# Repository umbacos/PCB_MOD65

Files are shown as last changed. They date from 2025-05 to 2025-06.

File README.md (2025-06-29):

# Mod65 Keyboard

![Mod65]

* **Keyboard Maintainer**: [umbacos](https://github.com/umbacos)
* **Firmware**: [QMK](https://qmk.fm/)
* **Source**: https://github.com/umbacos/MOD65

MOD65 is a custom mechanical keyboard designed and built 
by [umbacos](https://github.com/umbacos). It features a custom PCB based on
the [Aryess](https://github.com/pioz/aryess_keyboard) design but with some
improvements and differences.

## Features

* **RP2040 Pro Micro**
* **68% ANSI layout**
* **Rotary encoder (knob)**
* **[Unified Daughterboard](https://unified-daughterboard.github.io)** support
* **RGB Matrix LEDs** (per-key RGB lighting)
* **Underglow LED strip**
* **Configurable physical toggle switch**
* **OLED display**
* **O-ring gasket mount** (Friction fit)
* **PCB compatible with most 68% cases **
* **Built-in [Pomodoro Timer](https://en.wikipedia.org/wiki/Pomodoro_Technique)**
* **Fully open source**
  * **PCB and plate designed with [KiCad 9](https://www.kicad.org/)**
  * **Case designed with [Autodesk Fusion 360](https://www.autodesk.com/products/fusion-360/overview/)**

## Built it yourself

You can build your own **MOD65** keyboard by following these steps.

### Order the PCB and Plate

The PCB and plate production files are ready for you. You only need to upload them to JLCPCB:

* **PCB Production File:** `pcb/production/mod65_2.zip`
* **Plate Production File:** `plate/production/mod65_plate_2.zip`

Go to [https://jlcpcb.com/](https://jlcpcb.com/), and upload both files.

When ordering the PCB:

* Select the **PCB Assembly** option.
* JLCPCB will take care of soldering the components for you.
* Minimum order quantity is 5 units.

You will receive fully assembled PCBs at home.

### Order the Case

For the case, upload the file `case/MOD65 Case.step` to a 3D printing service.
You can use any 3D printing service if you prefer.

### Purchase the Extra Components

You will need some additional components. Here is the full list with purchase links:

| Component | Description | Purchase Link |
| --- | --- | --- |
| **OLED Display** | SSD1306 OLED 128 x 32 | [Buy on Amazon](https://www.amazon.it/dp/B079H2C7WH) |
| **JST Cables** | 3x JST 4-pin 1mm pitch cables | |
| | 1x JST 3-pin 1mm pitch cable | |
| **Rubber Feet** | Round 20mm diameter rubber feet | [Buy on Amazon](https://www.amazon.it/dp/B089SH84C4) |
| **Rotary Encoder** | Rotary encorder (EC11 compatible) | [Buy on Amazon](https://www.amazon.it/dp/B0B63YN466) |
| **Knob** | Metal knob for rotary encoder | [Buy on Amazon](https://www.amazon.it/dp/B0CRRDYKQK) |
| **LED Strip** | APA102-compatible LED strip, \~27.5cm | [Buy on Amazon](https://www.amazon.it/dp/B0B3HDNFVM) |
| **Stabilizers** | MX compatible keyboard stabilizers | [Buy on Amazon](https://www.amazon.it/dp/B01LW5B69T) |
| **Toggle Switch** | On/Off switch | [Buy on Amazon](https://www.amazon.it/dp/B07J4KB38W) |
| **Unified Daughterboard** | USB-C daughterboard | [Buy on 42keebs](https://42keebs.eu/shop/parts/unified-daughterboard-udb-c3-c4-c5/?attribute_version=C5%20JSH) |
| **O-Ring Gasket** | VMQ-50 (Silicone 50 duro), AS568-264  | [Buy on Amazon](https://www.amazon.it/dp/B07CVKV6DV) |
| **Foam Sheet** | Foam for case/PCB dampening | [Buy on Amazon](https://www.amazon.it/dp/B0CNVRGXWB) |

Some items can be found from different sellers depending on your country.

### Assembly

Once you have received the PCB, plate, case, and all components, you can start assembling your MOD65 keyboard.

## Compile the Firmware

```sh
qmk compile -kb umbacos/mod65 -km default
```

This command compiles the firmware for the MOD65 keyboard using the `default` keymap.

---

## Flash the Firmware

To flash the firmware, you must enter **boot mode** on the PCB.

### Entering Boot Mode

* If no firmware is present, connecting the board via USB will automatically
  enter boot mode.
* If firmware is already flashed:

  * Hold the **BOOT** button located on the PCB, then plug in the USB
    cable. Release the button once connected.
  * Alternatively, if this firmware is already running, press the key
    combination: `FN2 + ENTER`.

### Flashing

Once in boot mode, your computer should detect a new USB mass storage device
named something like `RPI-RP2`.

Copy the compiled `.uf2` file (e.g., `umbacos/mod65_default.uf2`) directly into the
root of that device. The board will automatically flash and reboot with the
new firmware.

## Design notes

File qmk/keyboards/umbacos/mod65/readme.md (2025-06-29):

# MOD65 Keyboard

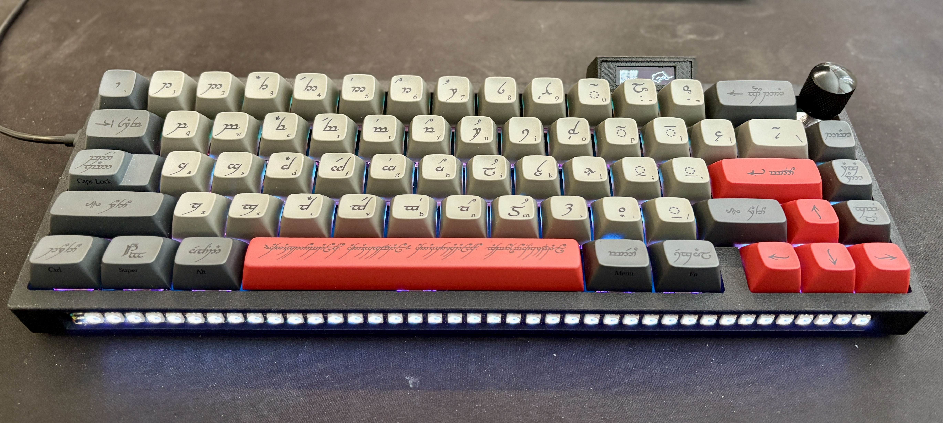
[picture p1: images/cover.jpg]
MOD65


* **Keyboard Maintainer**: [umbacos](https://github.com/umbacos)
* **Firmware**: [QMK](https://qmk.fm/)
* **Source**: https://github.com/umbacos/MOD65_keyboard

MOD65 is a custom mechanical keyboard designed and built from the ground up
by [umbacos](https://github.com/umbacos). It features a completely custom PCB and a
wide range of modern features for both productivity and aesthetics.

## Features

* **RP2040 Pro Micro**
* **65% ANSI layout**
* **Rotary encoder (knob)**
* **[Unified Daughterboard](https://unified-daughterboard.github.io)** support
* **RGB Matrix LEDs** (per-key RGB lighting)
* **Underglow LED strip**
* **Configurable physical toggle switch**
* **OLED display**
* **O-ring gasket mount** (Friction fit)
* **PCB compatible with [Bakeneko](https://github.com/kkatano/bakeneko-65) case**
* **Built-in [Pomodoro Timer](https://en.wikipedia.org/wiki/Pomodoro_Technique)**
* **Fully open source**
  * **PCB and plate designed with [KiCad 9](https://www.kicad.org/)**
  * **Case designed with [Autodesk Fusion 360](https://www.autodesk.com/products/fusion-360/overview/)**

---

## Compile the Firmware

```sh
qmk compile -kb MOD65 -km default
```

This command compiles the firmware for the MOD65 keyboard using the `default` keymap.

---

## Flash the Firmware

To flash the firmware, you must enter **boot mode** on the PCB.

### Entering Boot Mode

* If no firmware is present, connecting the board via USB will automatically
  enter boot mode.
* If firmware is already flashed:

  * Hold the **BOOT** button located underneath the PCB, then plug in the USB
    cable. Release the button once connected.
  * Alternatively, if this firmware is already running, press the key
    combination: `FN2 + ENTER`.

### Flashing

Once in boot mode, your computer should detect a new USB mass storage device
named something like `RPI-RP2`.

Copy the compiled `.uf2` file (e.g., `MOD65_default.uf2`) directly into the
root of that device. The board will automatically flash and reboot with the
new firmware.

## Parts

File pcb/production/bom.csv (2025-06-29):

Designator | Footprint | Quantity | Value | LCSC Part #
BTN1 | SW_SPST_TL3342 | 1 | RESET | C2886898
BTN2 | SW_SPST_TL3342 | 1 | BOOT | C2886898
C1, C10, C11, C2, C3, C4, C5, C6, C7, C8, C9 | 0805 | 11 | 100nf | C28233
C12, C13, C16, C17 | 0805 | 4 | 1uf | C28323
C14, C15 | 0805 | 2 | 22pf | C1804
D1, D10, D11, D12, D13, D14, D15, D16, D17, D18, D19, D2, D20, D21, D22, D23, D24, D25, D26, D27, D28, D29, D3, D30, D31, D32, D33, D34, D35, D36, D37, D38, D39, D4, D40, D41, D42, D43, D44, D45, D46, D47, D48, D49, D5, D50, D51, D52, D53, D54, D55, D56, D57, D58, D59, D6, D60, D61, D62, D63, D64, D65, D66, D67, D68, D7, D8, D9 | D_SOD-323 | 68 | D | C2128
J1 | JST_SH_SM04B-SRSS-TB_1x04-1MP_P1.00mm_Horizontal | 1 | UD | C160404
J2 | JST_SH_SM04B-SRSS-TB_1x04-1MP_P1.00mm_Horizontal | 1 | OLED | C160404
J3 | JST_SH_SM04B-SRSS-TB_1x04-1MP_P1.00mm_Horizontal | 1 | LEDs | C160404
J4 | JST_SH_SM03B-SRSS-TB_1x03-1MP_P1.00mm_Horizontal | 1 | Switch | C160403
LED1, LED10, LED11, LED12, LED13, LED14, LED15, LED16, LED17, LED18, LED19, LED2, LED20, LED21, LED22, LED23, LED24, LED25, LED26, LED27, LED28, LED29, LED3, LED30, LED31, LED32, LED33, LED34, LED35, LED36, LED37, LED38, LED39, LED4, LED40, LED41, LED42, LED43, LED44, LED45, LED46, LED47, LED48, LED49, LED5, LED50, LED51, LED52, LED53, LED54, LED55, LED56, LED57, LED58, LED59, LED6, LED60, LED61, LED62, LED63, LED64, LED65, LED66, LED67, LED68, LED7, LED8, LED9 | LED_6028R | 68 | SK6812MINI-E | C5149201
R1, R4, R5 | 0805 | 3 | 10k | C17414
R2, R3 | 0805 | 2 | 27 | C17594
R6 | 0805 | 1 | 1k | C17513
SW1 | SW_MX_HS_CPG151101S11_1u | 1 | ESC | C41430893
SW10 | SW_MX_HS_CPG151101S11_1u | 1 | 9 | C41430893
SW11 | SW_MX_HS_CPG151101S11_1u | 1 | 0 | C41430893
SW12 | SW_MX_HS_CPG151101S11_1u | 1 | - | C41430893
SW13 | SW_MX_HS_CPG151101S11_1u | 1 | = | C41430893
SW14 | SW_MX_HS_CPG151101S11_1u | 1 | BACK | C41430893
SW15 | SW_MX_HS_CPG151101S11_1u | 1 | Del | C41430893
SW15E1 | ROT_Alps_EC11E-Switch | 1 | SW15
SW16 | SW_MX_HS_CPG151101S11_1u | 1 | TAB | C41430893
SW17 | SW_MX_HS_CPG151101S11_1u | 1 | Q | C41430893
SW18 | SW_MX_HS_CPG151101S11_1u | 1 | W | C41430893
SW19 | SW_MX_HS_CPG151101S11_1u | 1 | E | C41430893
SW2 | SW_MX_HS_CPG151101S11_1u | 1 | 1 | C41430893
SW20 | SW_MX_HS_CPG151101S11_1u | 1 | R | C41430893
SW21 | SW_MX_HS_CPG151101S11_1u | 1 | T | C41430893
SW22 | SW_MX_HS_CPG151101S11_1u | 1 | Y | C41430893
SW23 | SW_MX_HS_CPG151101S11_1u | 1 | U | C41430893
SW24 | SW_MX_HS_CPG151101S11_1u | 1 | I | C41430893
SW25 | SW_MX_HS_CPG151101S11_1u | 1 | O | C41430893
SW26 | SW_MX_HS_CPG151101S11_1u | 1 | P | C41430893
SW27 | SW_MX_HS_CPG151101S11_1u | 1 | [ | C41430893
SW28 | SW_MX_HS_CPG151101S11_1u | 1 | ] | C41430893
SW29 | SW_MX_HS_CPG151101S11_1u | 1 | \ | C41430893
SW3 | SW_MX_HS_CPG151101S11_1u | 1 | 2 | C41430893
SW30 | SW_MX_HS_CPG151101S11_1u | 1 | PgUp | C41430893
SW31 | SW_MX_HS_CPG151101S11_1u | 1 | CAPS | C41430893
SW32 | SW_MX_HS_CPG151101S11_1u | 1 | A | C41430893
SW33 | SW_MX_HS_CPG151101S11_1u | 1 | S | C41430893
SW34 | SW_MX_HS_CPG151101S11_1u | 1 | D | C41430893
SW35 | SW_MX_HS_CPG151101S11_1u | 1 | F | C41430893
SW36 | SW_MX_HS_CPG151101S11_1u | 1 | G | C41430893
SW37 | SW_MX_HS_CPG151101S11_1u | 1 | H | C41430893
SW38 | SW_MX_HS_CPG151101S11_1u | 1 | J | C41430893
SW39 | SW_MX_HS_CPG151101S11_1u | 1 | K | C41430893
SW4 | SW_MX_HS_CPG151101S11_1u | 1 | 3 | C41430893
SW40 | SW_MX_HS_CPG151101S11_1u | 1 | L | C41430893
SW41 | SW_MX_HS_CPG151101S11_1u | 1 | ; | C41430893
SW42 | SW_MX_HS_CPG151101S11_1u | 1 | ' | C41430893
SW43 | SW_MX_HS_CPG151101S11_1u | 1 | ENTER | C41430893
SW44 | SW_MX_HS_CPG151101S11_1u | 1 | PgDn | C41430893
SW45 | SW_MX_HS_CPG151101S11_1u | 1 | LSHIFT | C41430893
SW46 | SW_MX_HS_CPG151101S11_1u | 1 | Z | C41430893
SW47 | SW_MX_HS_CPG151101S11_1u | 1 | X | C41430893
SW48 | SW_MX_HS_CPG151101S11_1u | 1 | C | C41430893
SW49 | SW_MX_HS_CPG151101S11_1u | 1 | V | C41430893
SW5 | SW_MX_HS_CPG151101S11_1u | 1 | 4 | C41430893
SW50 | SW_MX_HS_CPG151101S11_1u | 1 | B | C41430893
SW51 | SW_MX_HS_CPG151101S11_1u | 1 | N | C41430893
SW52 | SW_MX_HS_CPG151101S11_1u | 1 | M | C41430893
SW53 | SW_MX_HS_CPG151101S11_1u | 1 | , | C41430893
SW54 | SW_MX_HS_CPG151101S11_1u | 1 | . | C41430893
SW55 | SW_MX_HS_CPG151101S11_1u | 1 | / | C41430893
SW56 | SW_MX_HS_CPG151101S11_1u | 1 | RSHIFT | C41430893
SW57 | SW_MX_HS_CPG151101S11_1u | 1 | UP | C41430893
SW58 | SW_MX_HS_CPG151101S11_1u | 1 | HOME | C41430893
SW59 | SW_MX_HS_CPG151101S11_1u | 1 | CTRL | C41430893
SW6 | SW_MX_HS_CPG151101S11_1u | 1 | 5 | C41430893
SW60 | SW_MX_HS_CPG151101S11_1u | 1 | SUPER | C41430893
SW61 | SW_MX_HS_CPG151101S11_1u | 1 | ALT | C41430893
SW62 | SW_MX_HS_CPG151101S11_1u | 1 | SPACE | C41430893
SW63 | SW_MX_HS_CPG151101S11_1u | 1 | FN2 | C41430893
SW64 | SW_MX_HS_CPG151101S11_1u | 1 | FN1 | C41430893
SW65 | SW_MX_HS_CPG151101S11_1u | 1 | LEFT | C41430893
SW66 | SW_MX_HS_CPG151101S11_1u | 1 | DOWN | C41430893
SW67 | SW_MX_HS_CPG151101S11_1u | 1 | RIGHT | C41430893
SW68 | SW_MX_HS_CPG151101S11_1u | 1 | RALT | C41430893
SW7 | SW_MX_HS_CPG151101S11_1u | 1 | 6 | C41430893
SW8 | SW_MX_HS_CPG151101S11_1u | 1 | 7 | C41430893
SW9 | SW_MX_HS_CPG151101S11_1u | 1 | 8 | C41430893
U1 | WSON-8-1EP_8x6mm_P1.27mm_EP3.4x4.3mm | 1 | Flash | C2927043
U2 | SOT-23-5 | 1 | V Reg | C3021084
U3 | QFN-56-1EP_7x7mm_P0.4mm_EP3.2x3.2mm | 1 | RP2040 | C2040
Y1 | Crystal_SMD_3225-4Pin_3.2x2.5mm | 1 | Crystal | C93234

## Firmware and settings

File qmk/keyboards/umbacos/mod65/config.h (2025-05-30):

#pragma once

// Layers
#define MAC 0
#define WIN 1
#define FN1 2
#define FN2 3

// OLED pins
#define I2C_DRIVER I2CD0 // i2c0, require mcuconf.h
#define I2C1_SDA_PIN GP24
#define I2C1_SCL_PIN GP25

// OLED config
#define OLED_TIMEOUT 600000 // 10 minutes

// Lighting layers
#define RGBLIGHT_LAYERS
#define RGBLIGHT_LAYERS_OVERRIDE_RGB_OFF
#define RGBLIGHT_LAYER_BLINK
// #define RGB_MATRIX_DISABLE_SHARED_KEYCODES

// Custom features
#define TOGGLE_SWITCH
#define POMODORO

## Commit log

2025-05-30 Add source files
    [Aryess Case.f3d, Aryess Case.step, aryess.kicad_sch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]
2025-06-20 initial commit
    initial commit
    [MOD65.kicad_sch, aryess.kicad_sch, bom.csv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]
2025-06-29 JLCPCB 1
    [Aryess Case.f3d, Aryess Case.step, MOD65_plate.kicad_pcb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]
